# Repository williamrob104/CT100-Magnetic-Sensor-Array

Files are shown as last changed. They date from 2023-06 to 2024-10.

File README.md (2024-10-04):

# CT100 Magnetic Sensor Array

An 8×8 array of [CT100](https://www.allegromicro.com/-/media/files/datasheets/ct100-datasheet.pdf) magnetic sensors\
The spacing between sensors is 4 mm

## Hardware

The `sensor-board` directory contains the Altium Designer files for the sensor array PCB\
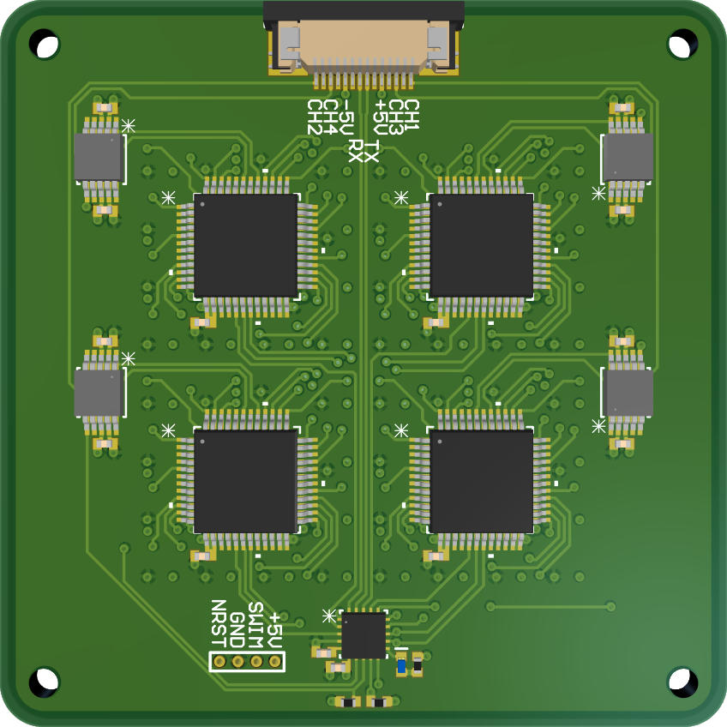
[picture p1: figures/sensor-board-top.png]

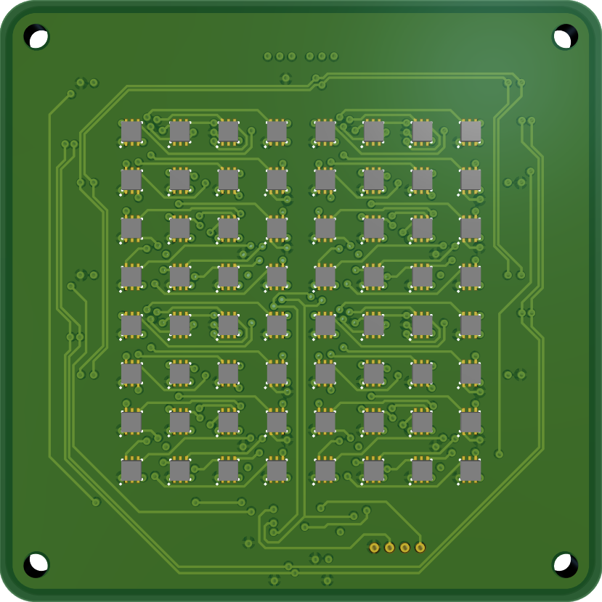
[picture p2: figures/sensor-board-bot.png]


The `interface-board` directory contains the Altium Designer files for the power regulation and signal amplification PCB that interfaces with the sensor array PCB\
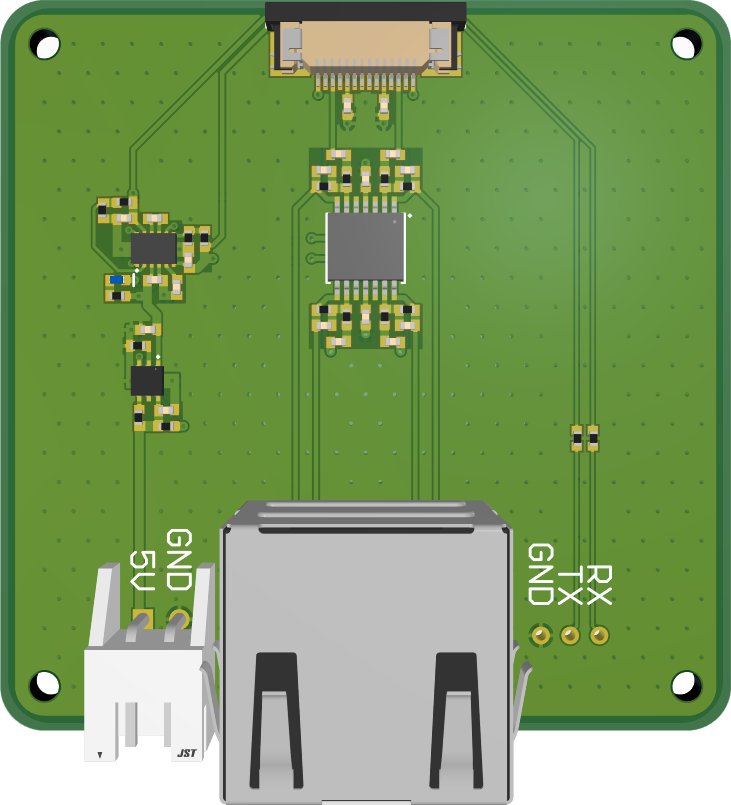
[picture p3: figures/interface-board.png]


The `coil-board` directory contains the KiCad files for the coil PCB\
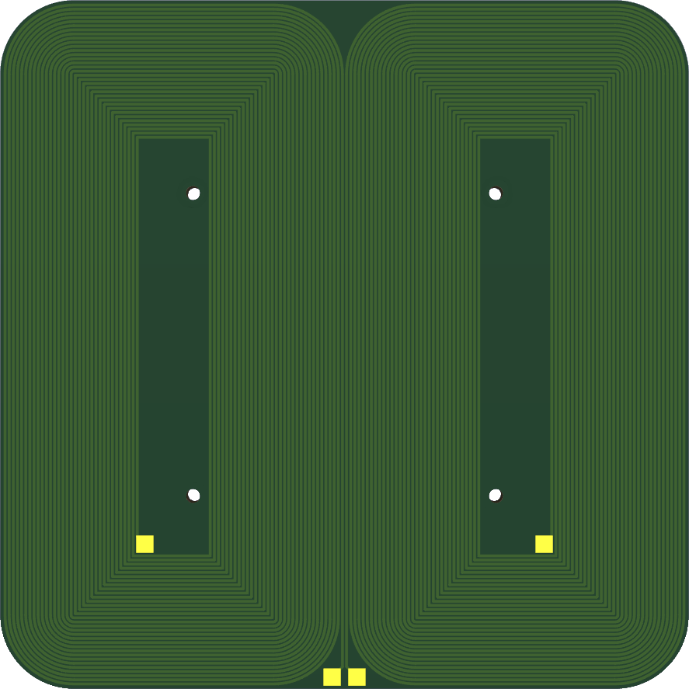
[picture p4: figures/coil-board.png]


## Firmware

The `sensor-board-firmware` directory contains the firmware for the onboard STM8S003F3U6 microcontroller (see [here](sensor-board-firmware/README.md) for more information)

## Software

The `data-acquisition` directory contains the MATLAB App to acquire data (see [here](data-acquisition/README.md) for more information)\
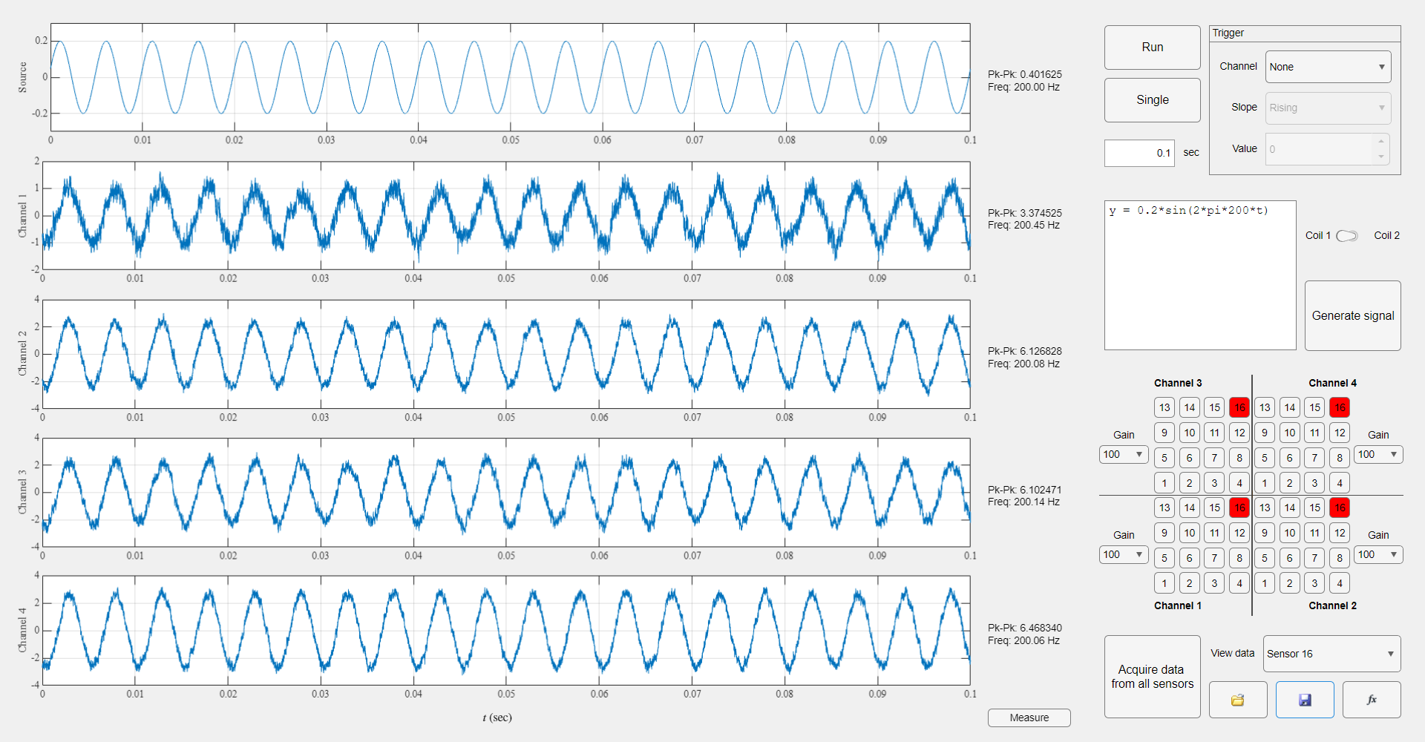
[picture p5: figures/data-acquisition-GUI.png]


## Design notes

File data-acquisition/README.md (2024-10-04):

## DAQ connection

- CH 4: Brown
- CH 2: Green
- CH 1: Blue
- CH 3: Orange

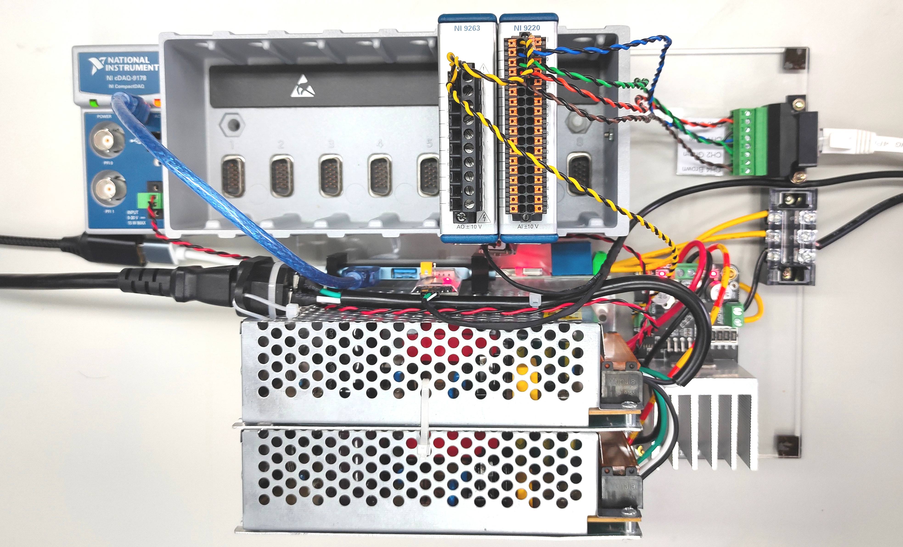
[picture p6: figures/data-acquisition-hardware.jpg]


## Develop

In **MyHardware.m**
- change the variables `deviceID` in function `connectDAQ` to the proper module ID
- change the variable `friendlyName` in functions `connectSensorSerial` and `connectRelaySerial` to the proper serial port friendly name

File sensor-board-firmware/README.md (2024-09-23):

## UART interface

The UART interface uses a baud of 115200. Each byte `c` received on the RX end is parsed as follows.

`c[7:6]` represents the channel number\
`c[5:4]` represents the gain on that channel\
`c[3:0]` represents the sensor which the channel is switched to

When the gain setting and sensor switching is finished, the same byte is echoed on the TX end.

## Develop

Download [ST Visual Develop](https://www.st.com/en/development-tools/stvd-stm8.html) and [Cosmic STM8 compiler (require registration)](https://www.cosmicsoftware.com/download_stm8_free.php) to compile and program the firmware

An [ST-LINK/V2](https://cdn-shop.adafruit.com/970x728/2548-01.jpg) can be used to program the firmware onto the microcontroller

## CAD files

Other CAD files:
sensor-board-firmware/sensor-board-firmware.stp

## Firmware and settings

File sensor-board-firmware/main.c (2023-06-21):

#include "STM8S.h"

#define UART_TX GPIOD, GPIO_PIN_5
#define UART_RX GPIOD, GPIO_PIN_6

#define GAIN_A0 GPIOC, GPIO_PIN_3
#define GAIN_A1 GPIOB, GPIO_PIN_4
#define WR1     GPIOC, GPIO_PIN_7
#define WR2     GPIOB, GPIO_PIN_5
#define WR3     GPIOD, GPIO_PIN_2
#define WR4     GPIOA, GPIO_PIN_3

#define SPI_SCK GPIOC, GPIO_PIN_5
#define SPI_DIN GPIOC, GPIO_PIN_6
#define SYNC1   GPIOD, GPIO_PIN_3
#define SYNC2   GPIOA, GPIO_PIN_2
#define SYNC3   GPIOD, GPIO_PIN_4
#define SYNC4   GPIOA, GPIO_PIN_1

#define LED     GPIOC, GPIO_PIN_4

#define BAUD_RATE 115200u
#define LED_BLINK 200u  // ms

void setChannel(uint8_t channel, uint8_t gain, uint8_t sensor)
{
	/* channel = 0, 1, 2, 3
	   gain    = 0x00 ~ 0x11
	   sensor  = 0 ~ 15     */
	if (gain & 0b01) GPIO_WriteHigh(GAIN_A0); else GPIO_WriteLow(GAIN_A0);
	if (gain & 0b10) GPIO_WriteHigh(GAIN_A1); else GPIO_WriteLow(GAIN_A1);

	switch (channel) {
		case 0: GPIO_WriteLow(SYNC1); GPIO_WriteLow(WR1); break;
		case 1: GPIO_WriteLow(SYNC2); GPIO_WriteLow(WR2); break;
		case 2: GPIO_WriteLow(SYNC3); GPIO_WriteLow(WR3); break;
		case 3: GPIO_WriteLow(SYNC4); GPIO_WriteLow(WR4); break;
	}

	SPI_SendData(sensor & 0x0F);

	switch (channel) {
		case 0: GPIO_WriteHigh(SYNC1); GPIO_WriteHigh(WR1); break;
		case 1: GPIO_WriteHigh(SYNC2); GPIO_WriteHigh(WR2); break;
		case 2: GPIO_WriteHigh(SYNC3); GPIO_WriteHigh(WR3); break;
		case 3: GPIO_WriteHigh(SYNC4); GPIO_WriteHigh(WR4); break;
	}
}

main()
{
	uint8_t cmd;

	// configure clock
	CLK_HSIPrescalerConfig(CLK_PRESCALER_HSIDIV1);
	CLK_PeripheralClockConfig(CLK_PERIPHERAL_I2C,    DISABLE);
	CLK_PeripheralClockConfig(CLK_PERIPHERAL_TIMER4, DISABLE);
	CLK_PeripheralClockConfig(CLK_PERIPHERAL_TIMER2, DISABLE);
	CLK_PeripheralClockConfig(CLK_PERIPHERAL_AWU,    DISABLE);
	CLK_PeripheralClockConfig(CLK_PERIPHERAL_ADC,    DISABLE);

	// init GPIO
	GPIO_Init(GAIN_A0, GPIO_MODE_OUT_PP_LOW_SLOW);
	GPIO_Init(GAIN_A1, GPIO_MODE_OUT_PP_LOW_SLOW);
	GPIO_Init(WR1,     GPIO_MODE_OUT_PP_HIGH_SLOW);
	GPIO_Init(WR2,     GPIO_MODE_OUT_PP_HIGH_SLOW);
	GPIO_Init(WR3,     GPIO_MODE_OUT_PP_HIGH_SLOW);
	GPIO_Init(WR4,     GPIO_MODE_OUT_PP_HIGH_SLOW);

	GPIO_Init(SYNC1,   GPIO_MODE_OUT_PP_HIGH_SLOW);
	GPIO_Init(SYNC2,   GPIO_MODE_OUT_PP_HIGH_SLOW);
	GPIO_Init(SYNC3,   GPIO_MODE_OUT_PP_HIGH_SLOW);
	GPIO_Init(SYNC4,   GPIO_MODE_OUT_PP_HIGH_SLOW);

	GPIO_Init(LED,     GPIO_MODE_OUT_PP_HIGH_SLOW);

	// init SPI
	GPIO_Init(SPI_SCK, GPIO_MODE_OUT_PP_HIGH_FAST);
	GPIO_Init(SPI_DIN, GPIO_MODE_OUT_PP_HIGH_FAST);

	SPI_Init(SPI_FIRSTBIT_MSB,
	         SPI_BAUDRATEPRESCALER_4,
			 SPI_MODE_MASTER,
			 SPI_CLOCKPOLARITY_HIGH,
			 SPI_CLOCKPHASE_1EDGE,
			 SPI_DATADIRECTION_1LINE_TX,
			 SPI_NSS_SOFT, 0x07);
	SPI_Cmd(ENABLE);

	// init UART
	GPIO_Init(UART_TX, GPIO_MODE_OUT_PP_HIGH_FAST);
	GPIO_Init(UART_RX, GPIO_MODE_IN_PU_NO_IT);

	UART1_Init(BAUD_RATE,
	           UART1_WORDLENGTH_8D,
	           UART1_STOPBITS_1,
			   UART1_PARITY_NO,
			   UART1_SYNCMODE_CLOCK_DISABLE,
			   UART1_MODE_TXRX_ENABLE);
	UART1_Cmd(ENABLE);

	// init TIM
	TIM1_TimeBaseInit(15999u, TIM1_COUNTERMODE_UP, LED_BLINK-1, 0u);
	TIM1_SelectOnePulseMode(TIM1_OPMODE_SINGLE);
	TIM1_Cmd(ENABLE);

	// main loop
	while (1) {
		if (TIM1_GetFlagStatus(TIM1_FLAG_UPDATE) == SET) {
			TIM1_ClearFlag(TIM1_FLAG_UPDATE);
			GPIO_WriteReverse(LED);
			TIM1_Cmd(ENABLE);
		}

		if (UART1_GetFlagStatus(UART1_FLAG_RXNE) == RESET)
			continue;

		cmd = UART1_ReceiveData8();

		setChannel(cmd >> 6, (cmd >> 4) & 0b11, cmd & 0b1111);

		while (UART1_GetFlagStatus(UART1_FLAG_TXE) == RESET) {}
		UART1_SendData8(cmd);
	}
}

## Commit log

2023-03-16 Finish rough layout
    [CT100-array.SchDoc, CT100-channel.SchDoc, PCB.PcbDoc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]
2023-03-17 Add decoupling capacitor
    [CT100-array.SchDoc, CT100-channel.SchDoc, PCB.PcbDoc]
2023-03-20 Add Vcc and GND layer
    [CT100-array.SchDoc, PCB.PcbDoc, footprints.PcbLib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]
2023-03-21 Reorganize project
    [CT100-array.SchDoc, CT100-channel.SchDoc, PCB.PcbDoc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]
2023-03-22 Add MCU and debug pin
    [CT100-array.SchDoc, PCB.PcbDoc, footprints.PcbLib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]
2023-04-01 Finish routing
    [CT100-array.SchDoc, PCB.PcbDoc, PCB_Project.PrjPcb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]
2023-04-01 Add mounting holes and board shape
    [PCB.PcbDoc, PCB_Project.PrjPcb]
2023-04-02 Start coil PCB
    [coil-board.kicad_pcb, coil-board.kicad_sch]
2023-04-05 Python script to draw coil on PCB
2023-04-05 Add holes to coil generation script
2023-04-05 Implement arc trace
2023-04-09 Rename files
    [CT100-array.SchDoc, PCB.PcbDoc, sensor-board-project.PrjPcb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]
2023-04-10 Start interface board
    [footprints.PcbLib, interface-board-project.PrjPcb, interface-board.PcbDoc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]
2023-04-12 Start sensor board firmware
    [sensor-board-firmware.stp]
2023-04-12 Implement gain selection and channel switching
2023-04-12 Remove Vcap from VDD and refine layout
    [footprints.PcbLib, sensor-board-project.PrjPcb, sensor-board.PcbDoc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]
2023-04-13 Update programming pad size
    [footprints.PcbLib, sensor-board.PcbDoc, sensor-board.SchDoc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]
2023-04-13 Change LED pin and echo UART command
2023-04-13 Change to 0.5mm pitch FPC connector
    [footprints.PcbLib, sensor-board.PcbDoc, sensor-board.SchDoc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]
2023-04-15 Sensor board firmware blink LED when execute command
2023-04-15 Remove power LED from sensor board
    [sensor-board.PcbDoc, sensor-board.SchDoc]
2023-04-16 Change to independent channel gain on sensor board
    [sensor-board.PcbDoc, sensor-board.SchDoc]
2023-04-16 Implement sensor board firmware for independent channel gain
2023-04-16 Add power IC for interface board
    [footprints.PcbLib, interface-board-project.PrjPcb, interface-board.PcbDoc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]
2023-04-17 Layout power for interface board
    [footprints.PcbLib, interface-board.PcbDoc, interface-board.SchDoc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]
2023-04-17 Add non-inverting op-amp for interface board
    [footprints.PcbLib, interface-board.PcbDoc, interface-board.SchDoc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]
2023-04-17 Add coil and solder pad to coil board
    [coil-board.kicad_pcb, coil-board.kicad_sch]
2023-04-17 Add decoupling capacitor on interface board for sensor board
    [interface-board.PcbDoc, interface-board.SchDoc]
2023-04-18 Add polygon pour cutout in interface board
    [interface-board.PcbDoc]
2023-05-21 Add pull-up resistors to PB4 and PB5
    [sensor-board.PcbDoc, sensor-board.SchDoc]
2023-05-21 Add position silkscreen for magnetic sensors
    [footprints.PcbLib, sensor-board.PcbDoc]
2023-05-27 Start sensor board GUI
2023-06-12 Change cap and res values
    [interface-board.PcbDoc, interface-board.SchDoc, sensor-board.PcbDoc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]
2023-06-15 Add relay toggle button
2023-06-17 Implement sensor board GUI in matlab
2023-06-17 Remove python sensor board GUI since implemented in matlab
2023-06-20 Change connector pinout and silk screen
    [footprints.PcbLib, interface-board.PcbDoc, interface-board.SchDoc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]
2023-06-20 Change amp on interface board to high-pass filter
    [interface-board.PcbDoc, interface-board.SchDoc]
2023-06-21 Change sensor board serial port baud to 115200
2023-06-25 Reimplement slow Ylim and add scan button
2023-06-25 Highlight sensors during scanning
2023-06-26 Implement auto capture data from all sensors
2023-07-03 Allow setting all sensors gains with double click for auto data acquisition
